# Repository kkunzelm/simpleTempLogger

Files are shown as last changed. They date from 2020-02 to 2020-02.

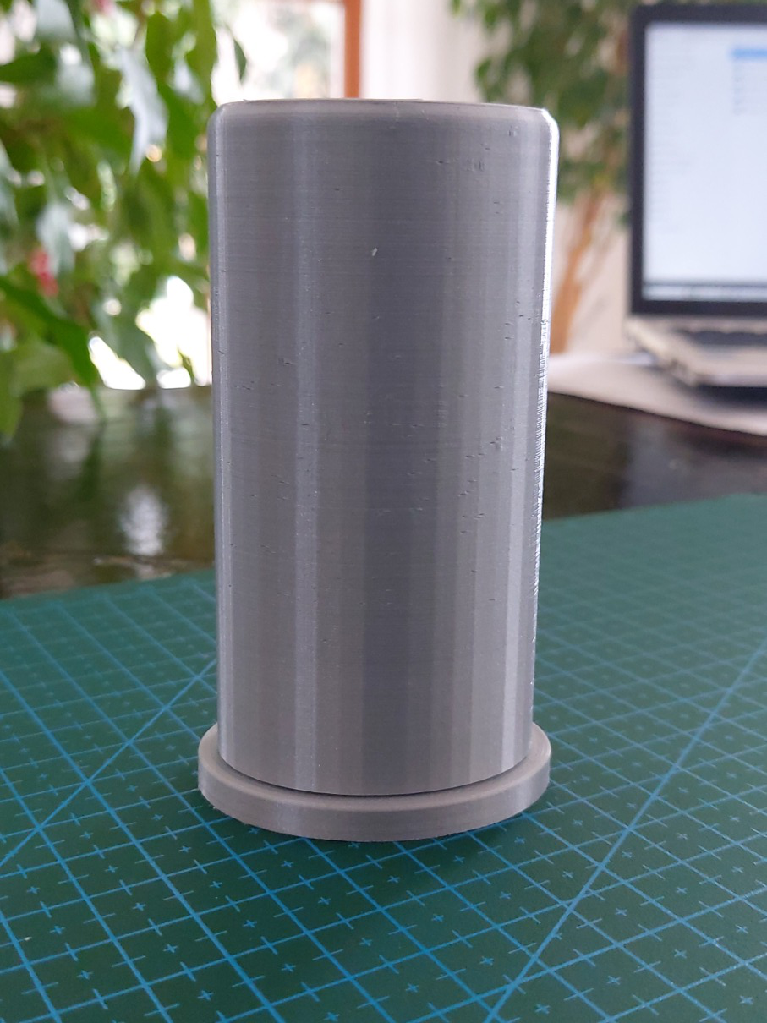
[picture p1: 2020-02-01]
images/case-outside-batteryside.jpg

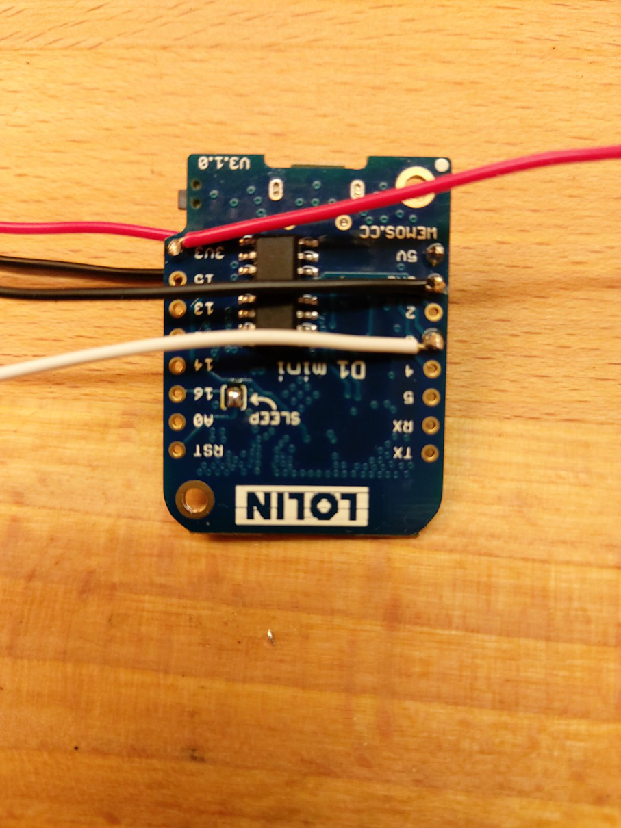
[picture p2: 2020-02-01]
images/D1-lowerside.jpg

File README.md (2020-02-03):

# simpleTempLogger

## Software

Temperature logger based on an ESP 8266 node delivering MQTT messages via WiFi. This sketch goes in deep sleep mode once the message string has been sent to the MQTT broker and wakes up periodically to repeat all steps.

* The MQTT message contains
  * the name of the influxdb database, i.e. telemetrie
  * location of the sensor: qth, see https://en.wikipedia.org/wiki/Maidenhead_Locator_System
  * sensor typ, i.e. DS18B20
  * sensorID, i.e. plain number, like 1, 2, 3 etc. or any descriptive string
  * temperature (or any other sensor value like humidity, air pressure etc. depending on sensors used)
* indirect measure of battery voltage. If the voltage is below a threshold level, the sensor stays in deep sleep until brown out occurs.
* unix time stamp as retrieved by the MCU client from a ntp server

Example of the current MQTT message format (InfluxDB line protocol format): 

    telemetrie,qth=JN58SD,sensor=DS18B20,number=2 temperature=22.87,voltage=3475 1579438238000000000

## Hardware

The code was implemented on a Wemos D1 mini (V 3.1), which is fed by a single 18650 lipo-cell. The entire assembly was mounted in a 3D printed housing. The battery contacts have the dimensions 18.5 mm x 16 mm x 0.3 mm. These contacts are relatively easy to find and buy online. 

The idea for the case came from http://www.thingiverse.com/thing:3116091. 

But I wanted to use the case as a freestanding indoor version. For this reason some modifications were necessary, so I redrew the case completely in Solidworks. 

Personally I think the idea of publishing stl files on Thingiverse is very good. Less good is that the original files of the CAD programs are not included. 

To make it easier for others to modify the case, I have archived my Solidworks files here. The files are also available in STL format. 

In my experience it would be sufficient to know some dimensions exactly. If you know your CAD program well enough, it is usually faster to redraw the parts anyway than to make changes to other CAD drawings. For this reason I have also added PDF files with the most important dimensions. 

The numerous holes on the mounting side of the battery compartment allow to mount different microcontrollers (e.g. Wemos D1 mini, Arduino nano, Adafruit Feather M4 or a 30 mm x 70 mm breadboard).

For this project I decided to make everything as simple as possible (KISS). For this reason I soldered all connections directly and did not use any plug contacts. The microcontroller was mounted on the battery compartment with self-tapping wood screws (SPAX, 3.0 x 12 mm) and the battery compartment was screwed to the base plate with self-tapping wood screws (SPAX 2.5 x 9 mm). 

## Documentation

You find a minimal documentation, how to setup a server to display your data based on the programs:

* Mosquitto -> Mosquitto.mkd
* Telegraf -> Telegraf.mkd
* InfluxDB -> InfluxDB.mkd
* Grafana -> Grafana.mkd

in the document folder "doc". Start with "MQTT-Telegraf-InfluxDB-Grafana.mkd".

## References

InfluxDB Line Protocol Tutorial [https://docs.influxdata.com/influxdb/v1.7/write_protocols/line_protocol_tutorial] last accessed Jan 2020

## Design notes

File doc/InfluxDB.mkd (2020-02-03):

Version from: February 2020

InfluxDB
========

InfluxDB is a time series database. Its command line syntax is similar to the SQL syntax. So far so good, but ... 

... again you have to learn a lot of new, mostly totally non-intuitive vocabulary to understand how to use InfluxDB.

The following sentences are examples from the introduction to InfluxDB:

from: https://docs.influxdata.com/influxdb/v1.7/concepts/key_concepts/

"In InfluxDB, a "series" is the collection of data that share a "retention policy", "measurement", and "tag set".

The "measurement" acts as a container for "tags", "fields", and the "time column". The measurement name is the description of the data that are stored in the associated fields. Measurement names are strings, and, for any SQL users out there, a measurement is conceptually similar to a table.

A single measurement can belong to different "retention policies". A retention policy describes how long InfluxDB keeps data (DURATION) and how many copies of this data is stored in the cluster (REPLICATION)."

The person responsible for such sentences should be dismissed immediately. I wonder why people all over the world put up with this nonsense. 

Install InfluxDB on Debian Buster
---------------------------------
from: https://computingforgeeks.com/install-influxdb-on-debian-10-buster-linux/

Install InfluxDB on Debian 10 (Buster) Linux

Add the official InfluxDB repository.

	sudo apt-get update
	sudo apt-get install gnupg2 curl wget
	wget -qO- https://repos.influxdata.com/influxdb.key | sudo apt-key add -
	echo "deb https://repos.influxdata.com/debian buster stable" | sudo tee /etc/apt/sources.list.d/influxdb.list

Once the repository is added, install InfluxDB on Debian 10 (Buster) Linux:

	sudo apt-get update
	sudo apt-get install influxdb

The InfluxDB default configuration file is located under /etc/influxdb/influxdb.conf. Most sections are commented out, you can modify it to your liking and restart influxdb service after.

Start and enable the service to start on boot up.

	sudo systemctl enable --now influxdb

Check status:

	~$ systemctl status influxdb

Open InfluxDB service ports on the firewall. For users using ufw firewall, allow service port.

	sudo apt-get install ufw
	sudo ufw enable
	sudo ufw allow 22/tcp
	sudo ufw allow 8086/tcp

By default, InfluxDB uses the following network ports:

* TCP port 8086 is used for client-server communication over InfluxDB’s HTTP API
* TCP port 8088 is used for the RPC service for backup and restore

Now check the opened ports on the system.

    sudo netstat -plntu

Whenever you need to run any InfluxDB commands on the terminal, you need to specify username using -username and password using -password options.

	influx -username 'username' -password 'password'

For curl, use -u to specify username and password separated by a colon.

	curl -G http://localhost:8086/query -u username:password --data-urlencode "q=SHOW DATABASES"

InfluxDB Data Model
-------------------
I will not try to reformulate the InfluxDB documentation. I simply mostly cite it from here on and add a few extra words where I think it is necessary.

from: https://docs.influxdata.com/influxdb/v1.7/concepts/key_concepts/
from: https://docs.influxdata.com/influxdb/v1.7/write_protocols/line_protocol_reference/#syntax

Citation begins:

The InfluxDB line protocol is a text based format for writing points to the database. Points must be in line protocol format for InfluxDB to successfully parse and write points.

Line protocol syntax

<measurement>[,<tag_key>=<tag_value>[,<tag_key>=<tag_value>]] <field_key>=<field_value>[,<field_key>=<field_value>] [<timestamp>]

[] = optional

InfluxDB line protocol tutorial
-------------------------------
from: https://docs.influxdata.com/influxdb/v1.7/write_protocols/line_protocol_tutorial/ = sehr hilfreich!

The InfluxDB line protocol is a text based format for writing data to the database. Data must be in line protocol format for InfluxDB to successfully parse and write points (unless you’re using a service plugin).

Using fictional temperature data, this page introduces InfluxDB line protocol. 

### Syntax

A single line of text in line protocol format represents one data point in InfluxDB. It informs InfluxDB of the point’s measurement, tag set, field set, and timestamp. The following code block shows a sample of line protocol and breaks it into its individual components:

	weather,location=us-midwest temperature=82 1465839830100400200
	  |    -------------------- --------------  |
	  |             |             |             |
	  |             |             |             |
	+-----------+--------+-+---------+-+---------+
	|measurement|,tag_set| |field_set| |timestamp|
	+-----------+--------+-+---------+-+---------+

Moving across each element in the diagram:

### Measurement

The name of the measurement that you want to write your data to. The measurement is required in line protocol.

In the example, the measurement name is weather.

### Tag set

The tag(s) that you want to include with your data point. Tags are optional in line protocol. Notice that the measurement and tag set are separated by a comma and no spaces.

Separate tag key-value pairs with an equals sign = and no spaces:

	<tag_key>=<tag_value>

Separate multiple tag-value pairs with a comma and no spaces:

	<tag_key>=<tag_value>,<tag_key>=<tag_value>

In the example, the tag set consists of one tag: location=us-midwest. Adding another tag (season=summer) to the example looks like this:

	weather,location=us-midwest,season=summer temperature=82 1465839830100400200

For best performance you should sort tags by key before sending them to the database. The sort should match the results from the Go bytes.Compare function.

### Whitespace I

Separate the measurement and the field set or, if you’re including a tag set with your data point, separate the tag set and the field set with a whitespace. The whitespace is required in line protocol.

Valid line protocol with no tag set:

	weather temperature=82 1465839830100400200

### Field set

The field(s) for your data point. Every data point requires at least one field in line protocol.

Separate field key-value pairs with an equals sign = and no spaces:

	<field_key>=<field_value>

Separate multiple field-value pairs with a comma and no spaces:

	<field_key>=<field_value>,<field_key>=<field_value>
	
In the example, the field set consists of one field: temperature=82. Adding another field (humidity=71) to the example looks like this:

	weather,location=us-midwest temperature=82,humidity=71 1465839830100400200

### Whitespace II

Separate the field set and the optional timestamp with a whitespace. The whitespace is required in line protocol if you’re including a timestamp.

### Timestamp

The timestamp for your data point in nanosecond-precision Unix time. The timestamp is optional in line protocol. If you do not specify a timestamp for your data point InfluxDB uses the server’s local nanosecond timestamp in UTC.

In the example, the timestamp is 1465839830100400200 (that’s 2016-06-13T17:43:50.1004002Z in RFC3339 format). The line protocol below is the same data point but without the timestamp. When InfluxDB writes it to the database it uses your server’s local timestamp instead of 2016-06-13T17:43:50.1004002Z.

	weather,location=us-midwest temperature=82

Use the InfluxDB API to specify timestamps with a precision other than nanoseconds, such as microseconds, milliseconds, or seconds. We recommend using the coarsest precision possible as this can result in significant improvements in compression. See the API Reference for more information.

### Setup hint:

Use the Network Time Protocol (NTP) to synchronize time between hosts. InfluxDB uses a host’s local time in UTC to assign timestamps to data; if hosts’ clocks aren’t synchronized with NTP, the timestamps on the data written to InfluxDB can be inaccurate.

### Data types

This section covers the data types of line protocol’s major components: measurements, tag keys, tag values, field keys, field values, and timestamps.

	Measurements, tag keys, tag values, and field keys are always strings.

Note: Because InfluxDB stores tag values as strings, InfluxDB cannot perform math on tag values. In addition, InfluxQL functions do not accept a tag value as a primary argument. It’s a good idea to take into account that information when designing your schema.

Timestamps are UNIX timestamps. The minimum valid timestamp is -9223372036854775806 or 1677-09-21T00:12:43.145224194Z. The maximum valid timestamp is 9223372036854775806 or 2262-04-11T23:47:16.854775806Z. As mentioned above, by default, InfluxDB assumes that timestamps have nanosecond precision. See the API Reference for how to specify alternative precisions.

Field values can be floats, integers, strings, or Booleans:

Floats - by default, InfluxDB assumes all numerical field values are floats.

Store the field value 82 as a float:

weather,location=us-midwest temperature=82 1465839830100400200
Integers - append an i to the field value to tell InfluxDB to store the number as an integer.

Store the field value 82 as an integer:

	weather,location=us-midwest temperature=82i 1465839830100400200

Strings - double quote string field values (more on quoting in line protocol below).

Store the field value too warm as a string:

	weather,location=us-midwest temperature="too warm" 1465839830100400200

Booleans - specify TRUE with t, T, true, True, or TRUE. Specify FALSE with f, F, false, False, or FALSE.

Store the field value true as a Boolean:

	weather,location=us-midwest too_hot=true 1465839830100400200

Note: Acceptable Boolean syntax differs for data writes and data queries. See Frequently Asked Questions for more information.

Within a measurement, a field’s type cannot differ within a shard, but it can differ across shards. For example, writing an integer to a field that previously accepted floats fails if InfluxDB attempts to store the integer in the same shard as the floats:

	> INSERT weather,location=us-midwest temperature=82 1465839830100400200
	> INSERT weather,location=us-midwest temperature=81i 1465839830100400300
	ERR: {"error":"field type conflict: input field \"temperature\" on measurement \"weather\" is type int64, already exists as type float"}
	But, writing an integer to a field that previously accepted floats succeeds if InfluxDB stores the integer in a new shard:

	> INSERT weather,location=us-midwest temperature=82 1465839830100400200
	> INSERT weather,location=us-midwest temperature=81i 1467154750000000000

Create InfluxDB Database and User
----------------------------------

You can access the content of InfluxDB databases via a command line interface, which is rather similar to the MySQL way of doing things. 

The first steps are explained here:

* https://docs.influxdata.com/influxdb/v1.7/tools/shell/

In order to store data from Telegraf, we need to set up the InfluxDB database and user.

InfluxDB provides the command line tool 'influx' for interacting with an InfluxDB server. 

Running

	influx

connects you to the default InfluxDB server on port '8086'.

Create a new database "sensors" and for example a user "telegraf" with the password "some-password" by running InfluxDB queries below.

	CREATE DATABASE sensors
	CREATE USER telegraf WITH password 'some-password'

Now check the database and user.

	SHOW DATABASES
	SHOW USERS

Make sure you get the database and user named 'telegraf' on the InfluxDB server.

Citation ends

Helpful example commands to beginn with
---------------------------------------

	CREATE DATABASE sensors
	SHOW DATABASES

	CREATE USER "telegraf" WITH PASSWORD "telegraf"
	GRANT all ON sensors TO telegraf

	USE sensors

	DROP DATABASE databaseToDelete

	SHOW TAG KEYS ON sensors
        SHOW FIELD KEYS ON sensors

Display the last data entries:

	USE sensors
	SELECT * FROM "sensors" WHERE time > now() - 1h

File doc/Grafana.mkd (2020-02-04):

Version from: February 2020

Grafana
=======

Grafana Intro
-------------

Grafana is used to visualize data. As usual you have to learn the Grafana specific language. They call a webpage with graphical elements a dashboard. The structure of the dashboard is similar to the structure of web pages using tables. The tables consist of cells called "panel" in Grafana jargon. Different types of graphics (i.e. line graphs, tables, single stat boxes, lists of alerts, pie charts etc.) can be positioned within a cell. One graphic is displayed per cell.

For the beginner it is completely unintuitive that he has to click on the title of a panel to edit the panel. But it is one of the most positive qualities of the human species that it can adapt to almost anything. Not that this is desirable to adapt to unintuitive programming requirements. But at least it helps to survive the sometimes very twisted logic of programmers. For example, the programmers at Grafana give the obvious symbol of a floppy disk the tool tip note, "Save dashboard". Unfortunately, they do not provide this help for the other symbols. When you hover your mouse over the title, you will see a "pointing finger" icon, but this does not suggest that you need to click on the title to edit the panel.

Important settings are hidden behind the Grafana logo in the upper left corner of the website. Finding this option also took me a while. Please also note the three very suttle vertical dots in the upper left corner of a panel. A click on them opens up further setting options.

But you get used to it, and then you can present your data very appealingly with relatively little effort. So it's worth the effort to fight your way through the initial frustration.

Install Grafana on Debian Buster
---------------------------------
from: https://computingforgeeks.com/how-to-install-grafana-6-on-ubuntu-18-04

### Helpful links:

* https://grafana.com/docs/grafana/latest/installation/debian/
* https://grafana.com/docs/grafana/latest/installation/configuration/

Grafana is not contained in the Debian standard repositories. Therefore we have to add a repository provided by the Grafana developers (for details see: https://grafana.com/docs/grafana/latest/installation/debian/).

Although we have done this several times in the meantime, I mention the following lines again for the sake of completeness. 

### Update system

	sudo apt-get update
	sudo apt-get upgrade
	sudo reboot

### Add Grafana APT repository

Add Grafana gpg key which allows you to install signed packages.

	sudo apt-get install -y gnupg2 curl
	curl https://packages.grafana.com/gpg.key | sudo apt-key add -

Then install Grafana APT repository:

	sudo add-apt-repository "deb https://packages.grafana.com/oss/deb stable main"

Once the repository is added, proceed to update your Apt repositories and install Grafana

	sudo apt-get update
	sudo apt-get install grafana

Start the Grafana service and check its status:

	sudo systemctl start grafana-server
    sudo systemctl status grafana-server
   	sudo systemctl enable grafana-server

Or:

    sudo service grafana-server start
    sudo service grafana-server status

Access Grafana on Debian / Ubuntu
----------------------------------

Once the service has been started, you can access its entry webpage by visiting the server IP on port 3000.

If you have an active firewall, for example ufw, allow port 3000 on the firewall.

	sudo ufw allow proto tcp from any to any port 3000

You can check the opened ports on the system.

    sudo netstat -plntu

Next open your browser and enter server IP address and port 3000.

Default logins are:

	Username: admin
	Password: admin

Change the login credentials immediately after authenticating.

Make Grafana display your data
==============================

In the beginning, Grafana is totally non-intuitive to use. Therefore, believe me: RTFM first!

### Helpful links:

* https://grafana.com/docs/grafana/latest/guides/basic_concepts/
* https://grafana.com/docs/grafana/latest/guides/getting_started/
* https://grafana.com/docs/grafana/latest/features/datasources/influxdb/

Testing the Connection Between InfluxDB, Mosquitto, and Telegraf
================================================================

We have configured all the components. To test if the connections are working let us start all the components if they aren't already running. 

## Mosquitto:

    mosquitto_sub -h name.of.your.server -t 'sensors'

    mosquitto_pub -h name.of.your.server -p 1883 -t 'your-topic' -m 'name-of-influx-database,tag1=string1,sensor=DS18B20 temp=28'

## Telegraf

For 'data_format = "influx"' the data must be sent in a certain format via MQTT.

Example

	telemetrie,qth=JM3AB,sensor=DS18B20 temperature=28

## InfluxDB

Open a terminal and use the command line syntax to display the latest data.

* https://docs.influxdata.com/influxdb/v1.7/tools/shell/

Example

	use sensors
	SELECT * FROM "sensors" WHERE time > now() - 1h

## Creating the Dashboard Using Grafana

The last step is creating a webpage which displays one or more diagrams with your data. Grafana helps you a lot as soon as you have understood their vocabulary. They call the webpage with the diagrams a "dashboard". The first thing is connecting to the web interface of Grafana using this link:

	http://<URL-of-your-Grafana-server>:3000

Now, follow these steps:

- Login to Grafana using (admin/admin)
- Configure the data source selecting for example InfluxDB
- Create your "dashboard" with graphs as you prefer

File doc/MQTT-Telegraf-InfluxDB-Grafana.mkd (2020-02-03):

Version from: February 2020

Preamble
========

I have seldom seen such a bad website design as the pages of InfluxDB and Grafana, although these websites are oriented to the current mainstream in terms of appearance. If you as a user are interested in understanding as fast as possible how to work with the offered software, you have to learn from tutorials of other users. The programmers of the websites of InfluxDB and Grafana show a lot of colorful pictures and use big words, but more than empty words can only be found with great effort on these websites. Users of all countries unite and defend yourselves against this colorful crap that is flooding us everywhere at the moment.

In addition, in our time it is a widespread bad habit in many areas of daily life to invent a new nomenclature in order to distinguish oneself from competitors, even for very similar problem solutions. As a result, one has to learn a lot of new vocabulary if one wants to familiarize oneself with a new topic.

It took me a while to understand the interaction of the programs MQTT, Telegraf, InfluxDB and Grafana, which are always mentioned in the context of sensor data as an elegant solution for data transfer, storage and display, as I had to learn a lot of new vocabulary. The enormous number of tutorials and instructions for the installation of these programs suggests that many others have experienced the same problems as I did and that many of these tutorials should serve as documentation of the efforts of the respective authors.

In the following I summarize my attempts to prepare and display the data I measured with my microcontrollers.

Most of it has already been described very well by others. As far as I can still remember, I quote my sources. Since many of these websites are no longer accessible after a short time, I extract the necessary information and summarize it in this document.

Excellent online tutorials to start with
========================================

* https://www.howtoforge.com/tutorial/how-to-install-tig-stack-telegraf-influxdb-and-grafana-on-ubuntu-1804/
* https://uriotnews.com/raspberry-pi-iot-sensors-influxdb-mqtt-and-grafana/
* https://dzone.com/articles/raspberry-pi-iot-sensors-influxdb-mqtt-and-grafana

Interaction of MQTT-Telegraf-InfluxDB-Grafana
=============================================

Principle
---------

Thanks to the successful development and distribution of the Arduino hardware and software over the last 10-15 years, many microcontrollers with different performance levels can now be easily programmed.

In combination with the microcontroller, numerous sensors are available to perform continuous measurement tasks. The microcontroller can take over the data acquisition and transmission. For a complex evaluation and graphic processing, a somewhat more powerful computer is usually required. For this reason, the data is usually transferred from the microcontroller to a PC for further processing.

The transfer requires that the microcontroller knows the target of the data transfer and that the microcontroller transfers the data in a "language" that is understandable for the target computer. The agreement on how the two communicate is called the "transmission protocol". It is convenient if the transmission protocol is easy to implement, openly available and fault-tolerant. MQTT meets the requirements of a transmission protocol almost perfectly for many measurement tasks.

Therefore MQTT is a widely used protocol with which telemetry data can be transmitted form the microcontroller to a computer.

New vocabulary related to MQTT are for example "MQTT broker", "publishing" and "subscribing". You could just as well say that an MQTT server receives the data sent by the microcontroller and makes it available to other programs for further processing. 

A very well known program that acts as MQTT broker is Mosquitto. Mosquitto can run as a background process (daemon). Mosquitto only receives the data and distributes it.

In order to be able to store the data permanently, you can use a database, for example.

The "translation" of the data between the MQTT protocol and the database format can be done by another program.

In principle, you could use any database for this task. However, since the measurement data are transmitted as time series, one can use time series databases optimized for this task. A widely used open source time series database is InfluxDB.The conversion of the MQTT data into a format understandable for InfluxDB is done by the program Telegraf.

Last, but not least, we need a program with which the time series database can be accessed and which ideally acts as a web server for the graphical presentation of the data. This task is often performed by the program Grafana.

In short
--------

These programs are often installed, configured and used on a server for collecting, storing and presenting data:

* Mosquitto: Mosquitto acts as MQTT "broker" accepting data coming from sensors, which are called "publisher" in MQTT lingo. The data are published under a so-called "topic".
* Telegraph: Telegraf "subscribes" to the "topic" of interest and makes this information for the time series database InfluxDB readable.
* InfluxDB: InfluxDB is an optimized time series database.
* Grafana: Grafana collects the data from InfluxDB and manages a "dashboard" to visualize such information

Install Guides for Telegraf, InfluxDB and Grafana (= TIG) on Debian Buster
==========================================================================

* https://computingforgeeks.com/install-and-configure-telegraf-on-debian-linux/
* https://computingforgeeks.com/install-influxdb-on-debian-10-buster-linux/
* https://computingforgeeks.com/how-to-install-grafana-6-on-ubuntu-18-04/

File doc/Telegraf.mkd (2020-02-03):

Version from: February 2020

Telegraf
========

Getting started with Telegraf
-----------------------------

Telegraf is a program which - in our case - subscribes to data which are published by our microcontroller to the MQTT broker Mosquitto and writes them into InfluxDB. I am just focusing on this special case that we subscribe to data from Mosquitto and output the data to InfluxDB. But telegraph could do much more.

Install Telegraf (Debian Buster) 
--------------------------------
from: https://computingforgeeks.com/install-and-configure-telegraf-on-debian-linux/

Update System

	sudo apt-get update 
	sudo apt-get upgrade
 
While InfluxDB is contained in the Debian repositories, I could not find Telegraf. Here the Debian maintainers should add a bit more work to complete their system. The InfluxDB from the Debian repository, however, is far behind the current version. Therefore add the Influxdata repository to get an up-to-date version.

Import repository GPG key.

    sudo apt-get install gnupg2 curl wget
    wget -qO- https://repos.influxdata.com/influxdb.key | sudo apt-key add -

Add InfluxDB APT repository using the command below.

    echo "deb https://repos.influxdata.com/debian buster stable" | sudo tee /etc/apt/sources.list.d/influxdb.list

Once the repository is added, install Telegraf on Debian 10 (Buster).

    sudo apt-get update
    sudo apt-get install telegraf

Configuring Telegraf
--------------------
mostly from: https://dzone.com/articles/raspberry-pi-iot-sensors-influxdb-mqtt-and-grafana

### Helpful links:

* https://github.com/influxdata/telegraf/tree/master/plugins/inputs/mqtt_consumer
* https://github.com/influxdata/telegraf/blob/master/docs/DATA_FORMATS_INPUT.md
* https://github.com/influxdata/telegraf/tree/master/plugins/parsers/influx

Configuration file location:

- Debian linux: /etc/telegraf/telegraf.conf

Before starting the Telegraf server you need to edit and/or create an initial configuration that specifies where your data come from and where your data should go. On linux systems, the default configuration file telegraf.conf is located in the '/etc/telegraf' directory. It is good practise to make a backup copy of the original file, before you edit it. 

The telegraf.conf file has four sections which might be of interest for our configuration.

These four sections have the headings: 

- 'Input Plugins'
- 'Processor Plugins'
- 'Aggregator Plugins'
- 'Output Plugins'

The example is taken from the InfluxDB/Telegraf documentation: 

* https://github.com/influxdata/telegraf/blob/release-1.13/plugins/inputs/mqtt_consumer/README.md

First we need to modify the "Input Plugin" section. In our case we use MQTT via Mosquitto. Therefore we have to add the "inputs.mqtt_consumer". To do this, we add the URL of the MQTT broker, which is the URL of the server, where Mosquitto is running. Please also add the port to which Mosquitto is listening. The next detail, which need individualization are the topics to which Telegraf should subscribe. Finally, we need to tell Telegraf the data format which is used to send the MQTT data to Mosquitto, this is done in the paragraph "## Data format to consume". Of the numerous data formats that the mqtt_consumer can process, the two formats "influx" and "value" are particularly important for us. 

	[[inputs.mqtt_consumer]]
	  ## MQTT broker URLs to be used. The format should be scheme://host:port,
	  ## schema can be tcp, ssl, or ws.
	  servers = ["tcp://127.0.0.1:1883"]

	  ## Topics that will be subscribed to.
	  topics = [
	    "sensors/location1/#",
	    "sensors/location2/#",
	  ]

     ... (commented lines are skipped here)...

	  ## Data format to consume.
	  ## Each data format has its own unique set of configuration options, read
	  ## more about them here:
	  ## https://github.com/influxdata/telegraf/blob/master/docs/DATA_FORMATS_INPUT.md
	  data_format = "influx"

#### Hint

For 'data_format = "influx"' the data must be sent in a certain format via MQTT.

Example: 

	temp,site=room1 value=28

Using this message, we are adding a measurement of the current temperature called "temp" with a tag named "site" which equals to "room1". The value of "temp" is 28.

This format is called InfluxDB line protocol and it is described in detail here:

* https://docs.influxdata.com/influxdb/v1.7/write_protocols/line_protocol_tutorial/

#### Another hint

In case you decide on the format "value", please note that you not only have to add the line ' data_format = "value"', but also have to define the data type integer, long, float, boolean or string with additional required line 'data_type = "...".  

Then, we need to modify the output section. Look for outputs.influxdb and add/modify the following lines:

	# Configuration for sending metrics to InfluxDB
	# Output Plugin InfluxDB
	[[outputs.influxdb]]
	  urls = [ "http://127.0.0.1:8086" ]
	  database = "<the-name-of-the-database-inside-influxdb>"
	  skip_database_creation = true
	  username = "<your-username-for-influxdb>"
	  password = "<your-password-for-influxdb>"	

Result
------

Restart the telegraf service and make sure there is no error.

Linux (sysvinit and upstart installations)

    service telegraf start

or just:

	/etc/init.d/telegraf start

Once Telegraf is up and running it will start collecting data and writing them to the desired output.

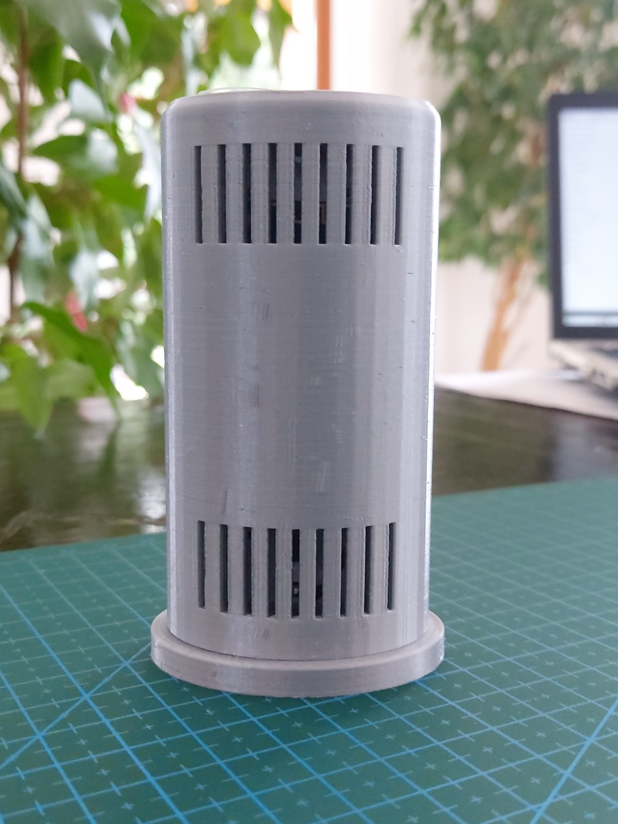
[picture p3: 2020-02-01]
images/case-outside-sensorside.jpg

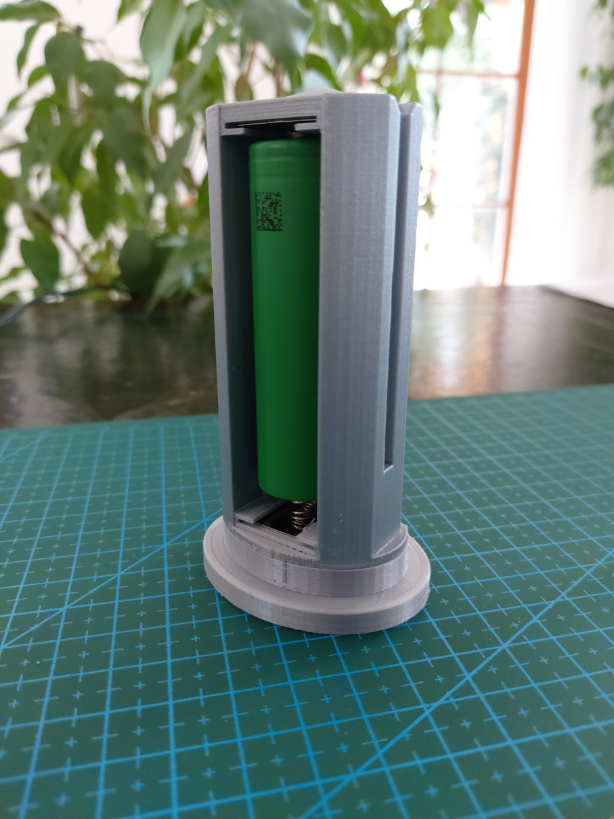
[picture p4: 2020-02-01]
images/batteryside.jpg

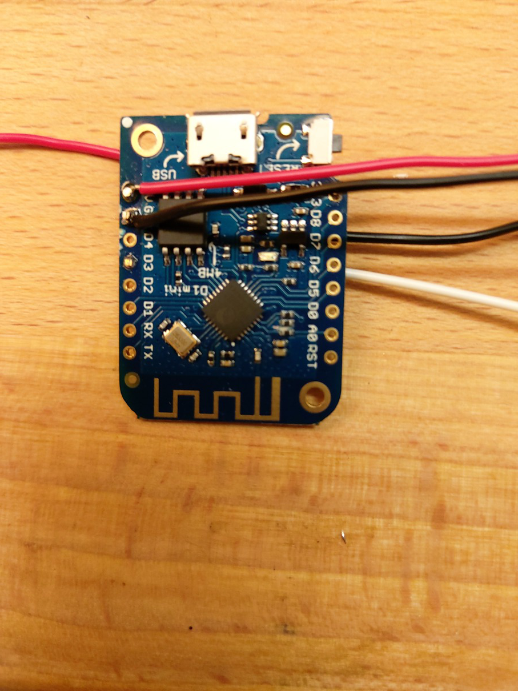
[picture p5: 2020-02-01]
images/D1-upperside.jpg

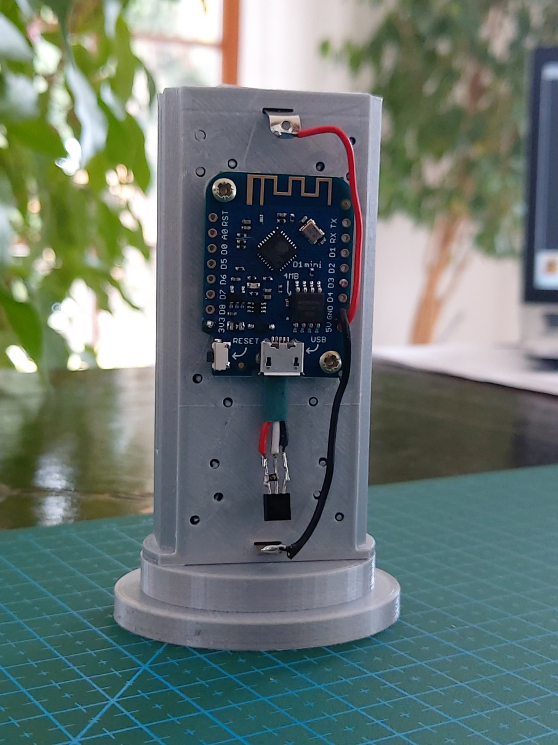
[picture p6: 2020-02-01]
images/sensorside.jpg

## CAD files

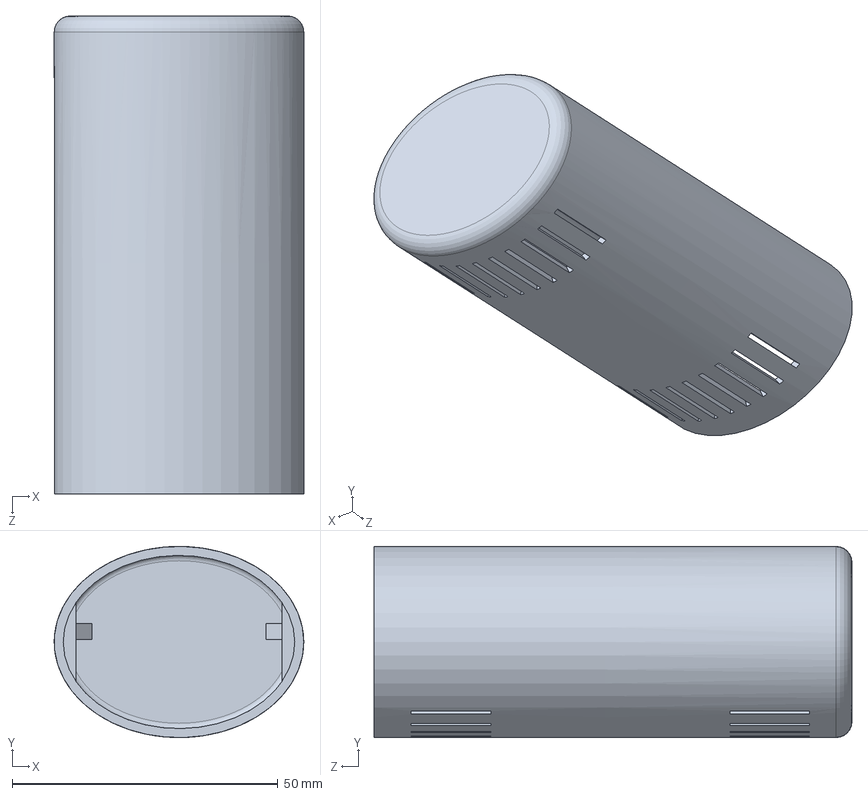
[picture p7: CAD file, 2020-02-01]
CAD/cover.SLDPRT
47.0 x 36.0 x 90.0 mm

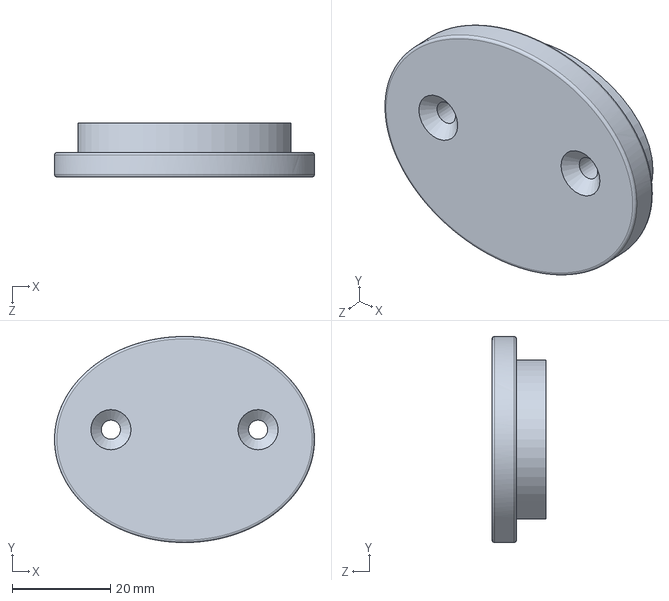
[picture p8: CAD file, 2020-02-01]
CAD/base.SLDPRT
53.0 x 42.0 x 11.0 mm

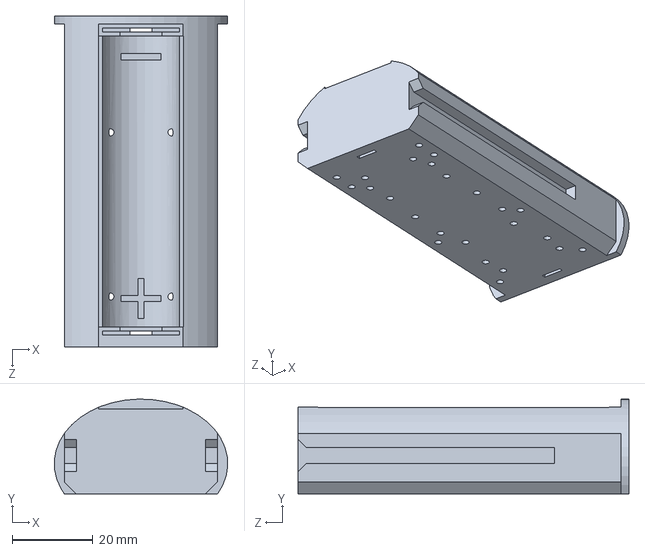
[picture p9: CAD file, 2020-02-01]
CAD/battery-box.SLDPRT
43.0 x 23.5 x 82.0 mm

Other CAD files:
CAD/base.STL
CAD/battery-box.SLDDRW
CAD/battery-box.STL
CAD/cover.STL

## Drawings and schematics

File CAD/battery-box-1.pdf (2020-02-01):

E E

F F

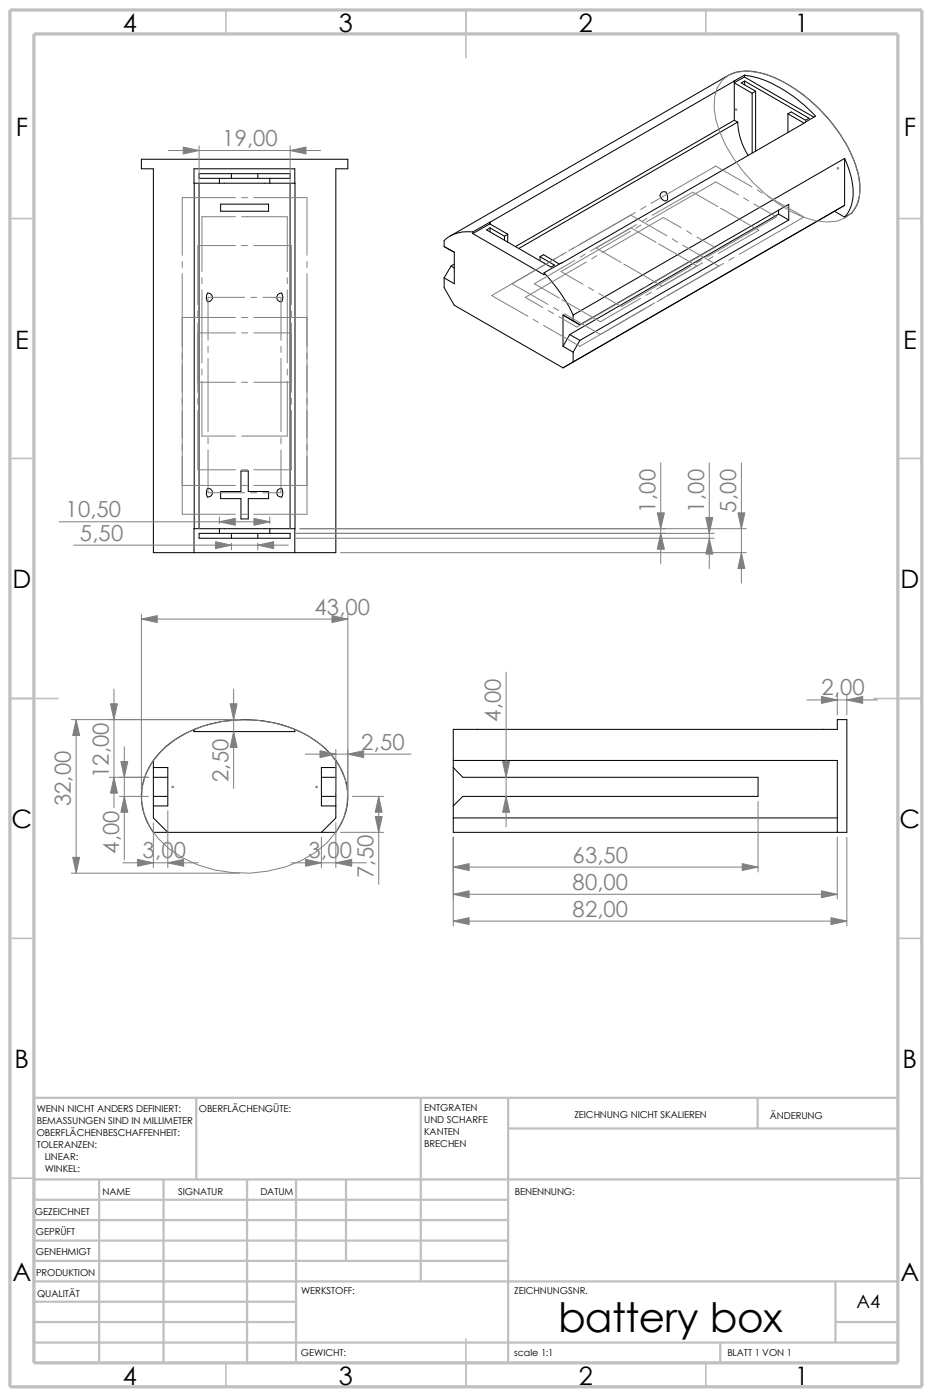
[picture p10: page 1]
QUALITÄT; PRODUKTION; battery box; GEWICHT:; scale 1:1; BLATT 1 VON 1; ZEICHNUNGSNR.; ZEICHNUNG NICHT SKALIEREN; ÄNDERUNG; WERKSTOFF:; OBERFLÄCHENGÜTE:; BRECHEN; ENTGRATEN; KANTEN; UND SCHARFE

WENN NICHT ANDERS DEFINIERT:
BEMASSUNGEN SIND IN MILLIMETER
OBERFLÄCHENBESCHAFFENHEIT:
TOLERANZEN:
LINEAR:
WINKEL:

NAME | SIGNATUR | DATUM | BENENNUNG:

GEZEICHNET
GEPRÜFT
GENEHMIGT

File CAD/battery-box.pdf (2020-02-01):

E E

F F

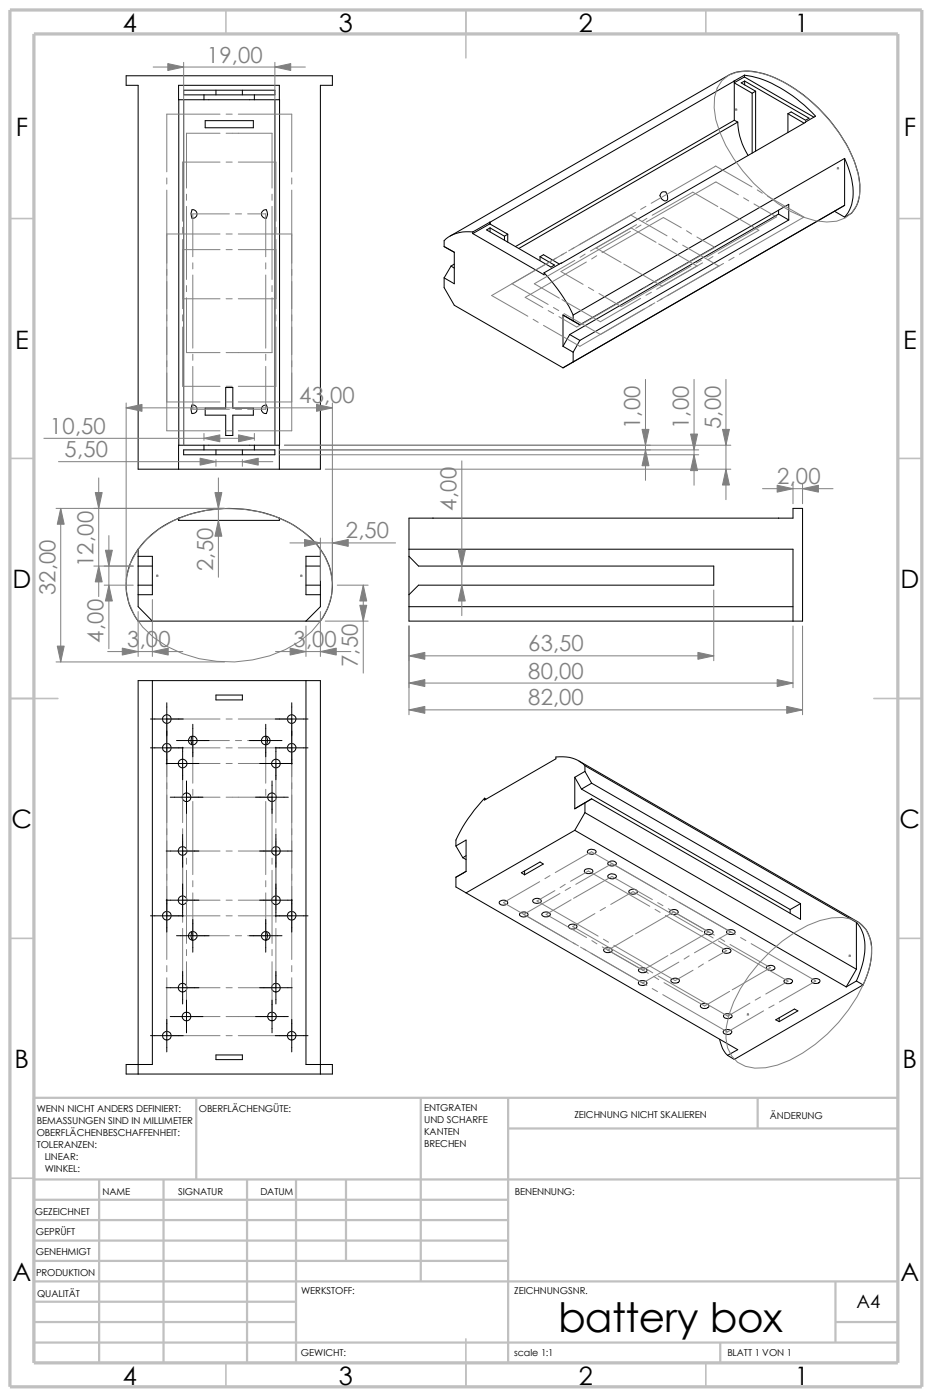
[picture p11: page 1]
battery box; GEWICHT:; scale 1:1; BLATT 1 VON 1; ZEICHNUNGSNR.; ZEICHNUNG NICHT SKALIEREN; ÄNDERUNG; WERKSTOFF:; PRODUKTION; QUALITÄT; BRECHEN; OBERFLÄCHENGÜTE:; KANTEN; UND SCHARFE; ENTGRATEN

WENN NICHT ANDERS DEFINIERT:
BEMASSUNGEN SIND IN MILLIMETER
OBERFLÄCHENBESCHAFFENHEIT:
TOLERANZEN:
LINEAR:
WINKEL:

NAME | SIGNATUR | DATUM | BENENNUNG:

GEZEICHNET
GEPRÜFT
GENEHMIGT

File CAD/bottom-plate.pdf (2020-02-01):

E E

53,00 ⁶,00 | 43,40

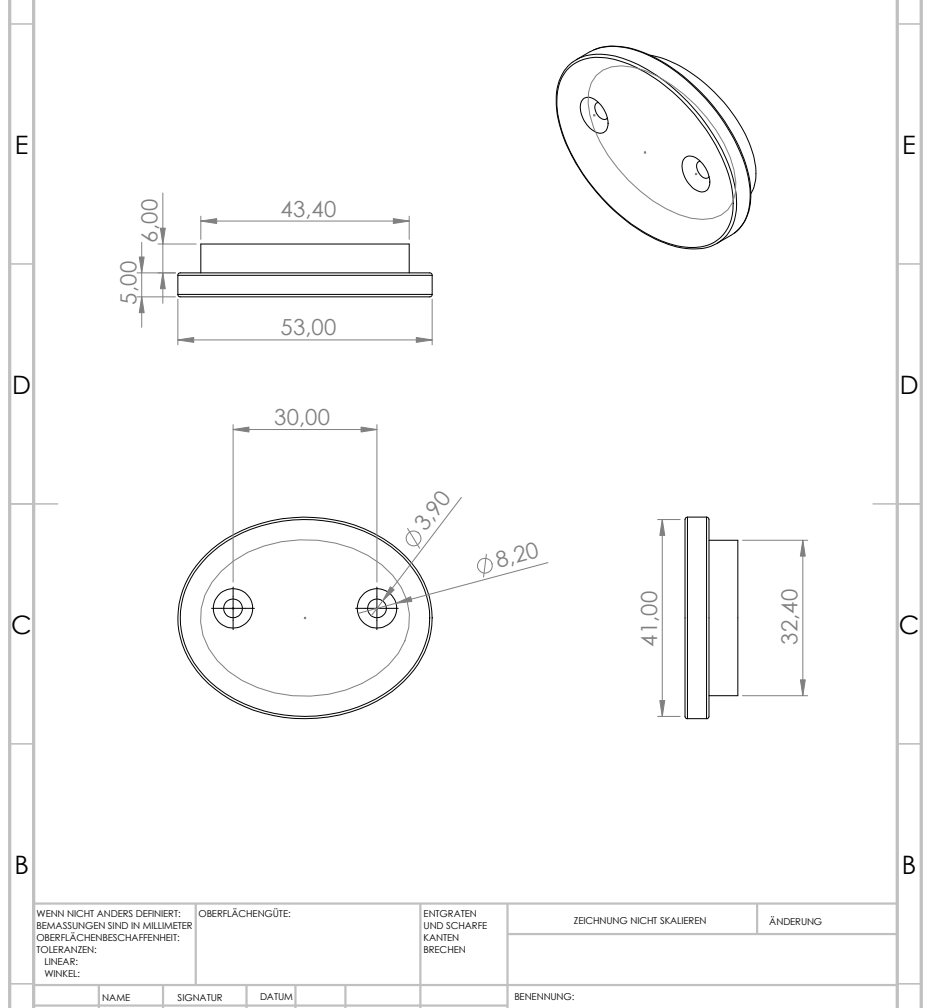
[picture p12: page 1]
BENENNUNG:; ZEICHNUNG NICHT SKALIEREN; ÄNDERUNG; NAME; SIGNATUR; DATUM; BRECHEN; OBERFLÄCHENGÜTE:; KANTEN; UND SCHARFE; ENTGRATEN

WENN NICHT ANDERS DEFINIERT:
BEMASSUNGEN SIND IN MILLIMETER
OBERFLÄCHENBESCHAFFENHEIT:
TOLERANZEN:
LINEAR:
WINKEL:

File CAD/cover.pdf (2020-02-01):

E E

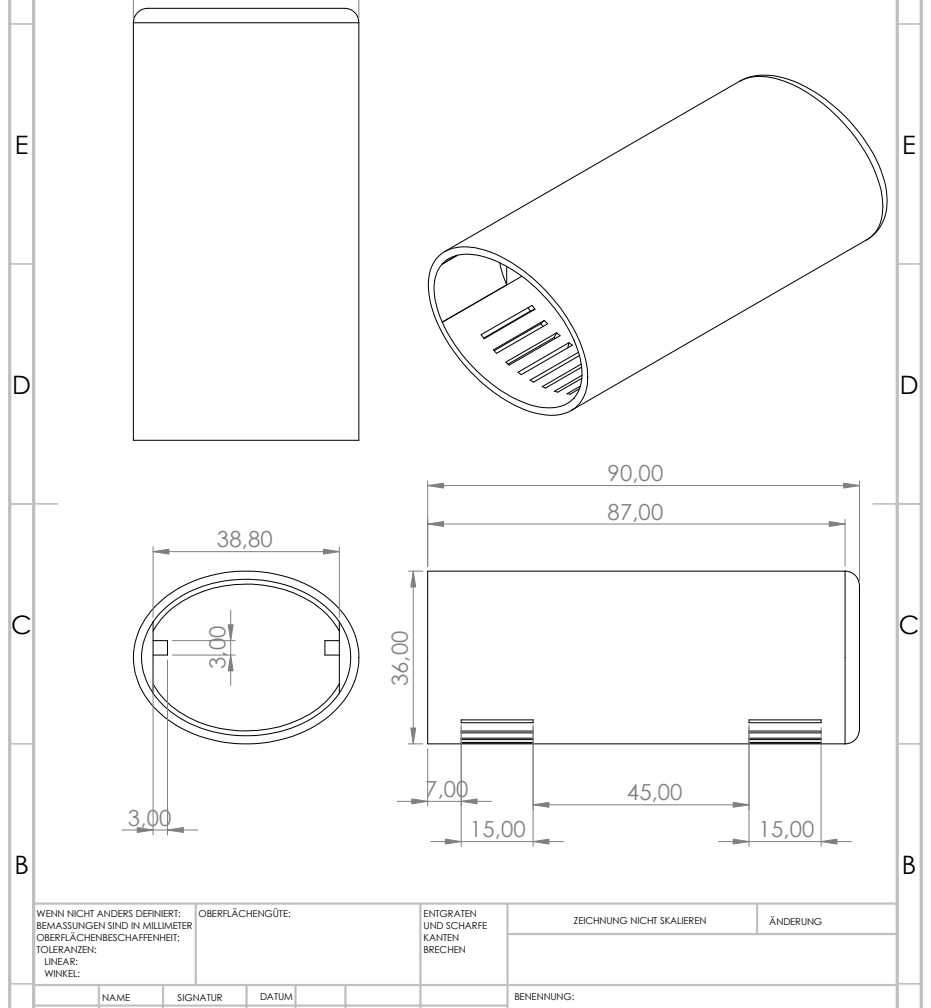
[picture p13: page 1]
BENENNUNG:; ZEICHNUNG NICHT SKALIEREN; ÄNDERUNG; NAME; SIGNATUR; DATUM; BRECHEN; OBERFLÄCHENGÜTE:; KANTEN; UND SCHARFE; ENTGRATEN; WINKEL:; LINEAR:

WENN NICHT ANDERS DEFINIERT:
BEMASSUNGEN SIND IN MILLIMETER
OBERFLÄCHENBESCHAFFENHEIT:
TOLERANZEN:

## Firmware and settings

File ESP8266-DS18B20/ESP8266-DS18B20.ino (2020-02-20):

/* The code is the documentation. To save myself time when I have to modify the code in the future
 * I will comment the code "vv" (= very verbose)! 
 * While this code uses much more strings then necessary it is easy to read and modify.
 *
 * Hardware: Wemos D1 mini V3.1 -> https://www.wemos.cc/en/latest/d1/d1_mini.html)
 * Last software modification: Jan 2020
 * Autor: KHK
 * 
 * Code based on:
 *     http://www.jerome-bernard.com/blog/2015/10/04/wifi-temperature-sensor-with-nodemcu-esp8266/
 *     and other internet sources.
 * 
 * Purpose: Sketch which publishes temperature data from a DS1820 sensor to a MQTT topic.  
 *
 *     Current message format: 
 *           telemetrie,qth=JN58SD,sensor=DS18B20,number=2 temperature=22.87,voltage=3475 1579438238000000000
 *
 *     The MQTT message contains
 *     - the name of the influxdb database, i.e. telemetrie
 *     - qth, see https://en.wikipedia.org/wiki/Maidenhead_Locator_System
 *     - sensortyp, i.e. DS18B20
 *     - sensorID, i.e. plain number, like 1, 2, 3 etc.
 *     - temperature (, humidity, etc depending on sensor)
 *     - indirect measure of battery voltage
 *     - unix time in ns as retrieved by the MCU client from a ntp server  
 *     - This sketch goes in deep sleep mode once the message string has been sent to the MQTT
 *       topic and wakes up periodically (configure SLEEP_DELAY_IN_SECONDS accordingly).
 *
 * Hookup guide:
 *   - to wake up from deep sleep: 
 *     connect D0 (GPIO16) pin to RST pin in order to enable the ESP8266 to wake up periodically.
 *     GPIO16 is connected to the internal RTC - real time clock, 
 *     which pulls the RST pin low when the timer has run down. 
 *     The D0/RST connection must be either removed for programming or 
 *     as an alternative approach: push the reset pin AND start uploading immediately
 *   - for DS18B20:
 *      + connect VCC (3.3V) to the appropriate DS18B20 pin (Vdd)
 *      + connect GND to the appopriate DS18B20 pin (GND)
 *      + connect D3 to the DS18B20 data pin (DQ) 
 *        annotation KHK: if you connect it to D4 as usually suggested the onboard LED will blink synchronous to 
 *                      every transmission. This is disturbing sometimes. Therefore I explicitely disable the 
 *                      onboard LED.
 *      + connect a 4.7K resistor between DQ and VCC.
 *    - Wemos D1 mini: see schematic here https://docs.wemos.cc/en/latest/_static/files/sch_d1_mini_v3.0.0.pdf
 *      cut the trace between R2 and R1 to allow a floating ADC, the cut removes R2 from ADC 
 *      the voltage divider from A0 to GND for ADC will no longer work!
 *    - Power from LiPo 18650 cell: connect GND to GND, connect the positive wire of the battery to +5V of D1 mini
 *      The +5V is before the onboard LDO thus the ESP8266 is powered from stabilized 3.3V.
 *
 * KHK additional comments: 
 *     - uses input pin D3 for DS18B20 so that the LED_BUILTIN can be disabled
 *       monitors internal voltage (https://electronza.com/esp8266-running-on-battery-power/)
 *       no voltage divider is used to monitor battery voltage to keep continous power consumption low 
 *     - added indirect voltage measurement to prepare for battery powering
 *     - added NTP service to identify duplicate messages in influxdb
 *     - use influxdb protocol format for MQTT message
 *     
 */

#include <ESP8266WiFi.h>             // wifi

#include <NTPClient.h>               // ntp
#include <WiFiUdp.h>                 // ntp

#include <PubSubClient.h>            // mqtt

#include <OneWire.h>                 // DS18B20
#include <DallasTemperature.h>       // DS18B20

#define SLEEP_DELAY_IN_SECONDS  30   // [s], the maximum sleep time is 4294967295 us, ~71 minutes.
#define ONE_WIRE_BUS            D3   // DS18B20 data pin

// WIFI credentials
const char* ssid = "XXXXXXXXXXXX";    
const char* password = "XXXXXXXXXXXX";

// Address of MQTT Broker
const char* mqtt_server = "XXXXXXXXXXXX"; //MQTT_BROKER_IP_ADDRESS

/* By default, Mosquitto will still allow anonymous connections, 
 * i.e. connections where no username/password is provided. 
 * In addition to the password_file entry, you also need: allow_anonymous false
 */
const char* mqtt_username = "";
const char* mqtt_password = "";
const char* mqtt_topic = "sensors";     // sensors is just an example

// individual MQTT message components

String databasename = "telemetrie";     // name of the influxdb database, telemetrie is just an example
String qthlocator = "JN58SD";           // JN58SD = München, just an example
String sensortype = "DS18B20";
String sensorID = "2";                  // 2 is just an example
String clientID = qthlocator + sensortype + sensorID;      // this clientID is just an example
String measuredProperty1 = "temperature";
String measuredProperty2 = "voltage";

// Text modules to compose MQTT message in influxdb line format 
// (https://docs.influxdata.com/influxdb/v1.7/write_protocols/line_protocol_tutorial/)
// String influxdbmessage1 = "telemetrie,qth=JN58SD,sensor=DS18B20,number=2 temperature=";
String influxdbmessage1 = databasename + 
                          ",qth="+
                          qthlocator+
                          ",sensor="+
                          sensortyp+
                          ",number="+
                          sensorID+
                          " "+
                          measuredProperty1+
                          "=";

// String influxdbmessage2 = ",voltage="; 
String influxdbmessage2 = ","+
                          measuredProperty2+
                          "=";

// ------------ nothing to edit beyond this point ------------

// Strings of numerical data for MQTT message
char temperatureString[6];
char voltageString[6];

// Monitoring Vin without external parts
// from https://electronza.com/esp8266-running-on-battery-power/
ADC_MODE(ADC_VCC);    // to check battery voltage
int Batt;             // to check battery voltage

const long utcOffsetInSeconds = 0;       // offset for ntp time zone, 0 = we stay with UTC

// Define NTP Client to get time
WiFiUDP ntpUDP;

/* By default 'pool.ntp.org' is used with 60 seconds update interval and no offset
 * You can specify the time server pool and the offset, (in seconds)
 * Additionaly you can specify the update interval (in milliseconds).
 * NTPClient timeClient(ntpUDP, "europe.pool.ntp.org", 3600, 60000);
 */

// Berlin: UTC+01:00  --> 01:00 is in h, for s use: 3600 
// It is good practice to use UTC, however!
NTPClient timeClient(ntpUDP, "europe.pool.ntp.org", utcOffsetInSeconds);

WiFiClient espClient;
PubSubClient client(espClient);

OneWire oneWire(ONE_WIRE_BUS);
DallasTemperature DS18B20(&oneWire);

// ********************************************************************************

void setup() {
  
       // Check battery status (https://electronza.com/esp8266-running-on-battery-power/)
       //     Reads Vin (not battery voltage!!! this is the voltage after the LDO)
       //     But Vin = battery voltage IF battery_voltage < 3.3V -> see datasheet of LDO

       Batt = ESP.getVcc();
       delay(100);

       // If the battery is discharged sleep as long as possible but don't go any further along this program!!!
       if(Batt < 3100){
          // Deep sleep for as long as you can
          ESP.deepSleep(ESP.deepSleepMax());
          delay(100);
       }
         
       // setup serial port
       Serial.begin(115200);

       // to make sure the LED is not consuming power
       // initialize digital pin LED_BUILTIN as an output
       pinMode(LED_BUILTIN, OUTPUT);
       digitalWrite(LED_BUILTIN, HIGH);   // turn the LED off -> Wemos D1 mini LED logic is inverted

       // output the battery value (https://electronza.com/esp8266-running-on-battery-power/)
       Batt = ESP.getVcc();
       Serial.println("Vin voltage is: ");  
       Serial.println(Batt);

       // setup WiFi
       setup_wifi();

       timeClient.begin();
         
       client.setServer(mqtt_server, 1883);
       client.setCallback(callback);

       // setup OneWire bus
       DS18B20.begin();
}

void setup_wifi() {
       delay(100);
       // We start by connecting to a WiFi network
       Serial.println();
       Serial.print("Connecting to ");
       Serial.println(ssid);

       WiFi.begin(ssid, password);

       while (WiFi.status() != WL_CONNECTED) {
           delay(500);
       Serial.print(".");
        }

       Serial.println("");
       Serial.println("WiFi connected");
       Serial.println("IP address: ");
       Serial.println(WiFi.localIP());
}

// KHK currently not used
void callback(char* topic, byte* payload, unsigned int length) {
       Serial.print("Message arrived [");
       Serial.print(topic);
       Serial.print("] ");
       for (int i = 0; i < length; i++) {
              Serial.print((char)payload[i]);
       }
       Serial.println();
}

void reconnect() {
       // Loop until we're reconnected
       while (!client.connected()) {
              Serial.print("Attempting MQTT connection...");
              // Attempt to connect
              if (client.connect(clientID.c_str(), mqtt_username, mqtt_password)) {
                     Serial.println("connected");
              } else {
                     Serial.print("failed, rc=");
                     Serial.print(client.state());
                     Serial.println(" try again in 1 second");
                     // Wait 1 seconds before retrying
                     delay(1000);
              }
       }
}

float getTemperature() {
       Serial.println("Requesting DS18B20 temperature...");
       float temp;
       do {
              DS18B20.requestTemperatures(); 

              // Plausibility check for temperature values
              if(DS18B20.getTempCByIndex(0) > -50 && DS18B20.getTempCByIndex(0) < 150){
                  temp = DS18B20.getTempCByIndex(0);
              }
              delay(1000);

       } while (temp == 85.0 || temp == (-127.0));     // The power-on reset value of the temperature register is +85°C.
                                                       // Error Code -127: #define DEVICE_DISCONNECTED_C -127
       return temp;
}

// ********************************************************************************

void loop() {
     
      if (!client.connected()) {
        reconnect();
      }
      client.loop();
    
      // send data to the MQTT topic
      // The publish functions expect char[] types to be passed in rather than Strings.
      // You need to use the String.toCharArray() function to convert your strings to the necessary type. Some say
      // that .c_str.() is the more elegant alternative 
      // (https://arduino.stackexchange.com/questions/518/is-it-better-to-use-c-str-or-tochararray)

      float temperature = getTemperature();
      // convert temperature to a string with two digits before the comma and 2 digits for precision
      dtostrf(temperature, 2, 2, temperatureString);

      // convert battery readings to string
      dtostrf(Batt, 2, 0, voltageString);
      
      timeClient.update();

      // compose MQTT message string
      // influxdb expects timestamps in [ns]
      // test with https://www.epochconverter.com/
      String message = influxdbmessage1 + 
                       temperatureString + 
                       influxdbmessage2 + 
                       voltageString + " " + 
                       String(timeClient.getEpochTime()) + "000000000";  
      
      Serial.println(message);
     
      client.publish(mqtt_topic, message.c_str());
    
      Serial.println("Closing MQTT connection...");
      client.disconnect();
    
      Serial.println("Closing WiFi connection...");
      WiFi.disconnect();
    
      delay(100);
    
      Serial.print("Entering deep sleep mode for ");
      Serial.print(SLEEP_DELAY_IN_SECONDS);
      Serial.println(" s");

      ESP.deepSleep(SLEEP_DELAY_IN_SECONDS * 1000000, WAKE_RF_DEFAULT);  
      // KHK to save even more power use: WAKE_NO_RFCAL
      // thus you disable wifi calibration when you return from deep sleep, 
      // you will avoid a power surge at this time 
      // example call: ESP.deepSleep(SLEEP_DELAY_IN_SECONDS * 1000000, WAKE_NO_RFCAL);
      delay(500);   // wait for deep sleep to happen
}

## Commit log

2020-02-01 folders with CAD files and images added
    [base.SLDPRT, base.STL, battery-box.SLDDRW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]
2020-02-19 added plausibility check for temperature values
